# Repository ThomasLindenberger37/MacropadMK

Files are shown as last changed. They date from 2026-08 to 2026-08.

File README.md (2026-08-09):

# MacropadMK

MacropadMK is a 12-key macropad built around the Waveshare ESP32-S3-Zero. The
board combines a diode-isolated 4 × 3 keyboard matrix, three USB-C power-entry
options, and two general-purpose JST-SH connections in a compact design.

The PCB is intended for an accessible prototyping workflow: order bare boards,
assemble and validate the first units by hand, then reuse the same LCSC-aware
bill of materials for a later JLCPCB assembly run.

## Design overview

- Controller: ESP32-S3-Zero
- Keyboard: 12 switches arranged as 4 rows × 3 columns
- Isolation: one diode per switch
- Matrix direction: `COL2ROW`
- Supply rails: `BOARD_5V`, `3V3`, and `GND`
- USB-C inputs: the controller connector plus two alternative PCB connectors
- Expansion: two identically pinned 3-position JST-SH connectors

## Keyboard matrix

The switches form a 4-row by 3-column matrix. `ROW1` through `ROW4` are scanned
one at a time by driving the selected row low. `COL1` through `COL3` are inputs,
each held high by an external 10 kΩ pull-up resistor to `3V3`.

Each key is an independent branch:

```text
COLx -> switch -> diode anode -> diode cathode -> ROWx
```

The diode orientation is `COL2ROW`: the cathode, identified by the stripe on the
physical diode, points toward the row line. When a selected row is low and a key
on that row is pressed, its column input is pulled low through the switch and
diode.

| Signal group | Quantity | Scan role | External bias |
| --- | ---: | --- | --- |
| `ROW1`–`ROW4` | 4 | Driven low individually | None |
| `COL1`–`COL3` | 3 | Digital inputs | 10 kΩ to `3V3` per column |

## USB-C power architecture

The ESP32-S3-Zero already has its own USB-C connector. The PCB provides two
additional connector positions as alternative 5 V inputs:

- Horizontal/right-angle: HRO `TYPE-C-31-M-12`
- Vertical/axial: `MC-110LD-L124`, USB 2.0, 16 pins, with THT mounting tabs
- Vertical connector LCSC/JLCPCB part number: `C3039282`

The additional connectors are currently used only for power. They are still
full USB 2.0 connector parts so that the same components and footprints can be
reused in future designs with USB data support.

Each additional receptacle follows these connection rules:

- Tie all VBUS pins of that receptacle together.
- Connect all GND pins to board ground.
- Connect `CC1` to GND through its own 5.1 kΩ resistor.
- Connect `CC2` separately to GND through its own 5.1 kΩ resistor.
- Connect the connector shield to GND.
- Leave `D+`, `D-`, `SBU1`, and `SBU2` unconnected and mark them as no-connect.

Each alternative receptacle feeds the common `BOARD_5V` rail through a separate
solder bridge. `BOARD_5V` connects to the ESP32-S3-Zero 5 V pin. An optional
resettable fuse rated for approximately 1 A can be fitted ahead of the shared
rail.

Place 10 µF bulk capacitance and 100 nF decoupling close to the 5 V input. Route
VBUS with approximately 0.8–1.0 mm wide traces; 0.25 mm traces are not
recommended for a 1 A supply path.

> **Power-source warning:** The board does not provide input OR-ing or reverse-
> current isolation. Only one USB power source may be connected at a time unless
> suitable input decoupling and source isolation are added.

## Additional connectors

The board provides two identically pinned 3-position JST-SH connectors with a
1.0 mm pitch.

- KiCad symbol: `Connector_Generic:Conn_01x03`
- KiCad footprint:
  `Connector_JST:JST_SH_SM03B-SRSS-TB_1x03-1MP_P1.00mm_Horizontal`

| Pin | Signal |
| ---: | --- |
| 1 | `GND` |
| 2 | `3V3` |
| 3 | Signal |

## Sourcing and assembly strategy

Components should use LCSC `C` part numbers wherever practical. The same part
numbers can be used both for loose component orders from LCSC and for JLCPCB
assembly BOM matching.

The intended manufacturing sequence is:

1. Order unassembled prototype PCBs.
2. Hand-assemble and electrically validate the first boards.
3. Resolve ERC/DRC findings and confirm footprints, polarity, and connector
   mechanics.
4. Reuse the validated BOM for a later JLCPCB assembly order.

## Project assets

[Download the schematic as PDF](assets/MacropadMK-schematic.pdf).

MacropadMK schematic

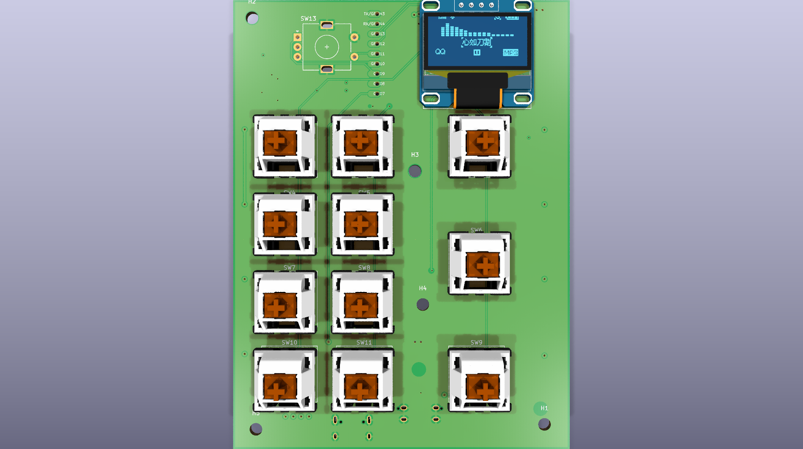
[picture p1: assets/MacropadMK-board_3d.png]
MacropadMK 3D board view


Some connector or encoder models may be absent from the rendered 3D preview if
their STEP files are not available locally. This does not affect the Gerber or
drill exports, but mechanical fit must still be checked before ordering.

## Fabrication and documentation exports

The repository contains its KiBot automation directly under `scripts/`. Docker
is required; the scripts use the KiCad 10 KiBot image configured in
`scripts/project.config.yaml`.

Generate the schematic PDF/SVG and the 3D preview:

```bash
./scripts/assets.sh
```

Generate Gerbers, drill files, BOM, placement data, the manufacturer ZIP, and
STEP models:

```bash
./scripts/fabrication.sh
```

Generated manufacturing files are written to `Fabrication/`. The validated
manufacturer archive is `Fabrication/MacropadMK-Gerber_Pack.zip`.

The relevant configuration files are:

- `scripts/project.config.yaml` — project name, KiCad image, PCB thickness, and
  mechanical-hole settings
- `scripts/kibot/config.kibot.yaml` — manufacturing outputs and production
  layers
- `scripts/kibot/kibot_assets.kibot.yaml` — documentation PDF, SVG, and 3D
  render outputs

Always run KiCad ERC and DRC and review the generated Gerbers before submitting
an order. Successful file generation does not imply that the electrical or
mechanical design is production-ready.

## Automated fabrication build

The GitHub Actions fabrication workflow generates manufacturing artifacts when
changes are pushed to the repository:



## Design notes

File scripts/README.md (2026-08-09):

# Scripts Workspace

This folder contains all automation related to:
- KiBot fabrication export
- STEP generation with mechanical holes from Gerber + Drill
- KiCad schematic field maintenance

## Structure

- `kibot/config.kibot.yaml`: Main KiBot config.
- `kibot/kibot_assets.kibot.yaml`: Assets KiBot config.
- `project.config.yaml`: Project-specific defaults (board name, output name, thickness, mechanical tools).
- `generate_step_mech.py`: Mechanical STEP generator.
- `add_lcsc_field.py`: Adds missing `LCSC` fields to placed schematic symbols.
- `fabrication.sh`: Fabrication pipeline (KiBot + mechanical STEP generator).
- `assets.sh`: Local assets pipeline (schematic + 3D render).
- `.venv/`: Local Python virtualenv used by script tooling.
- `.gitignore`: Ignore rules for script-local artifacts.

## Add missing LCSC fields

Preview the changes without modifying the schematic:

```bash
python3 scripts/add_lcsc_field.py --dry-run MacropadMK.kicad_sch
```

Apply them (close the schematic in KiCad first):

```bash
python3 scripts/add_lcsc_field.py MacropadMK.kicad_sch
```

Existing `LCSC` fields and their values remain unchanged. Power and helper symbols
such as `#PWR` and `#FLG` are skipped by default. Pass
`--include-power-symbols` if those symbols should receive the field too.

## Fabrication Script

Run:

```bash
./scripts/fabrication.sh
```

Behavior:
- Always runs inside Docker image `ghcr.io/inti-cmnb/kicad10_auto_full:latest`.

Default output name prefix comes from `output_name` in `scripts/project.config.yaml`.
If `output_name` is empty, repository folder name is used.
Override it with:

```bash
./scripts/fabrication.sh --name MyBoardName
```

Optional board base override:

```bash
./scripts/fabrication.sh --board MacropadMK
```

Optional mechanical tools override:

```bash
./scripts/fabrication.sh --mechanical-tools T5
```

## Assets Script (Local)

Run locally (uses Docker image `ghcr.io/inti-cmnb/kicad10_auto_full:latest`):

```bash
./scripts/assets.sh
```

Default asset prefix comes from `output_name` in `scripts/project.config.yaml`.
If `output_name` is empty, repository folder name is used.
Override it with:

```bash
./scripts/assets.sh --name MyBoardName
```

Optional board base override:

```bash
./scripts/assets.sh --board MacropadMK
```

## Project Config

Default config file: `scripts/project.config.yaml`

Example fields:

```yaml
board_name: MacropadMK
output_name: MacropadMK
thickness: 1.6
mechanical_tools:
docker_image: ghcr.io/inti-cmnb/kicad10_auto_full:latest
```

Both scripts read this file automatically.
CLI options always override config values.

Use a different config file:

```bash
./scripts/fabrication.sh --config scripts/project.config.yaml
./scripts/assets.sh --config scripts/project.config.yaml
```

## What `fabrication.sh` Does

1. Runs KiBot with `scripts/kibot/config.kibot.yaml`.
2. Installs `cadquery` in the Docker runtime.
3. Runs `generate_step_mech.py` to create:
   - `Fabrication/STEP/<name>-STEP_Mechanical.step`

## Manual Script Usage

```bash
scripts/.venv/bin/python scripts/generate_step_mech.py \
  --edge-gerber Fabrication/Gerber/MacropadMK-Edge_Cuts.gbr \
  --drill Fabrication/Drill/MacropadMK-drill.drl \
  --out Fabrication/STEP/MacropadMK-STEP_Mechanical.step \
  --thickness 1.6
```

To force mechanical tools explicitly:

```bash
scripts/.venv/bin/python scripts/generate_step_mech.py \
  --edge-gerber Fabrication/Gerber/MacropadMK-Edge_Cuts.gbr \
  --drill Fabrication/Drill/MacropadMK-drill.drl \
  --out Fabrication/STEP/MacropadMK-STEP_Mechanical.step \
  --thickness 1.6 \
  --mechanical-tools T3,T4
```

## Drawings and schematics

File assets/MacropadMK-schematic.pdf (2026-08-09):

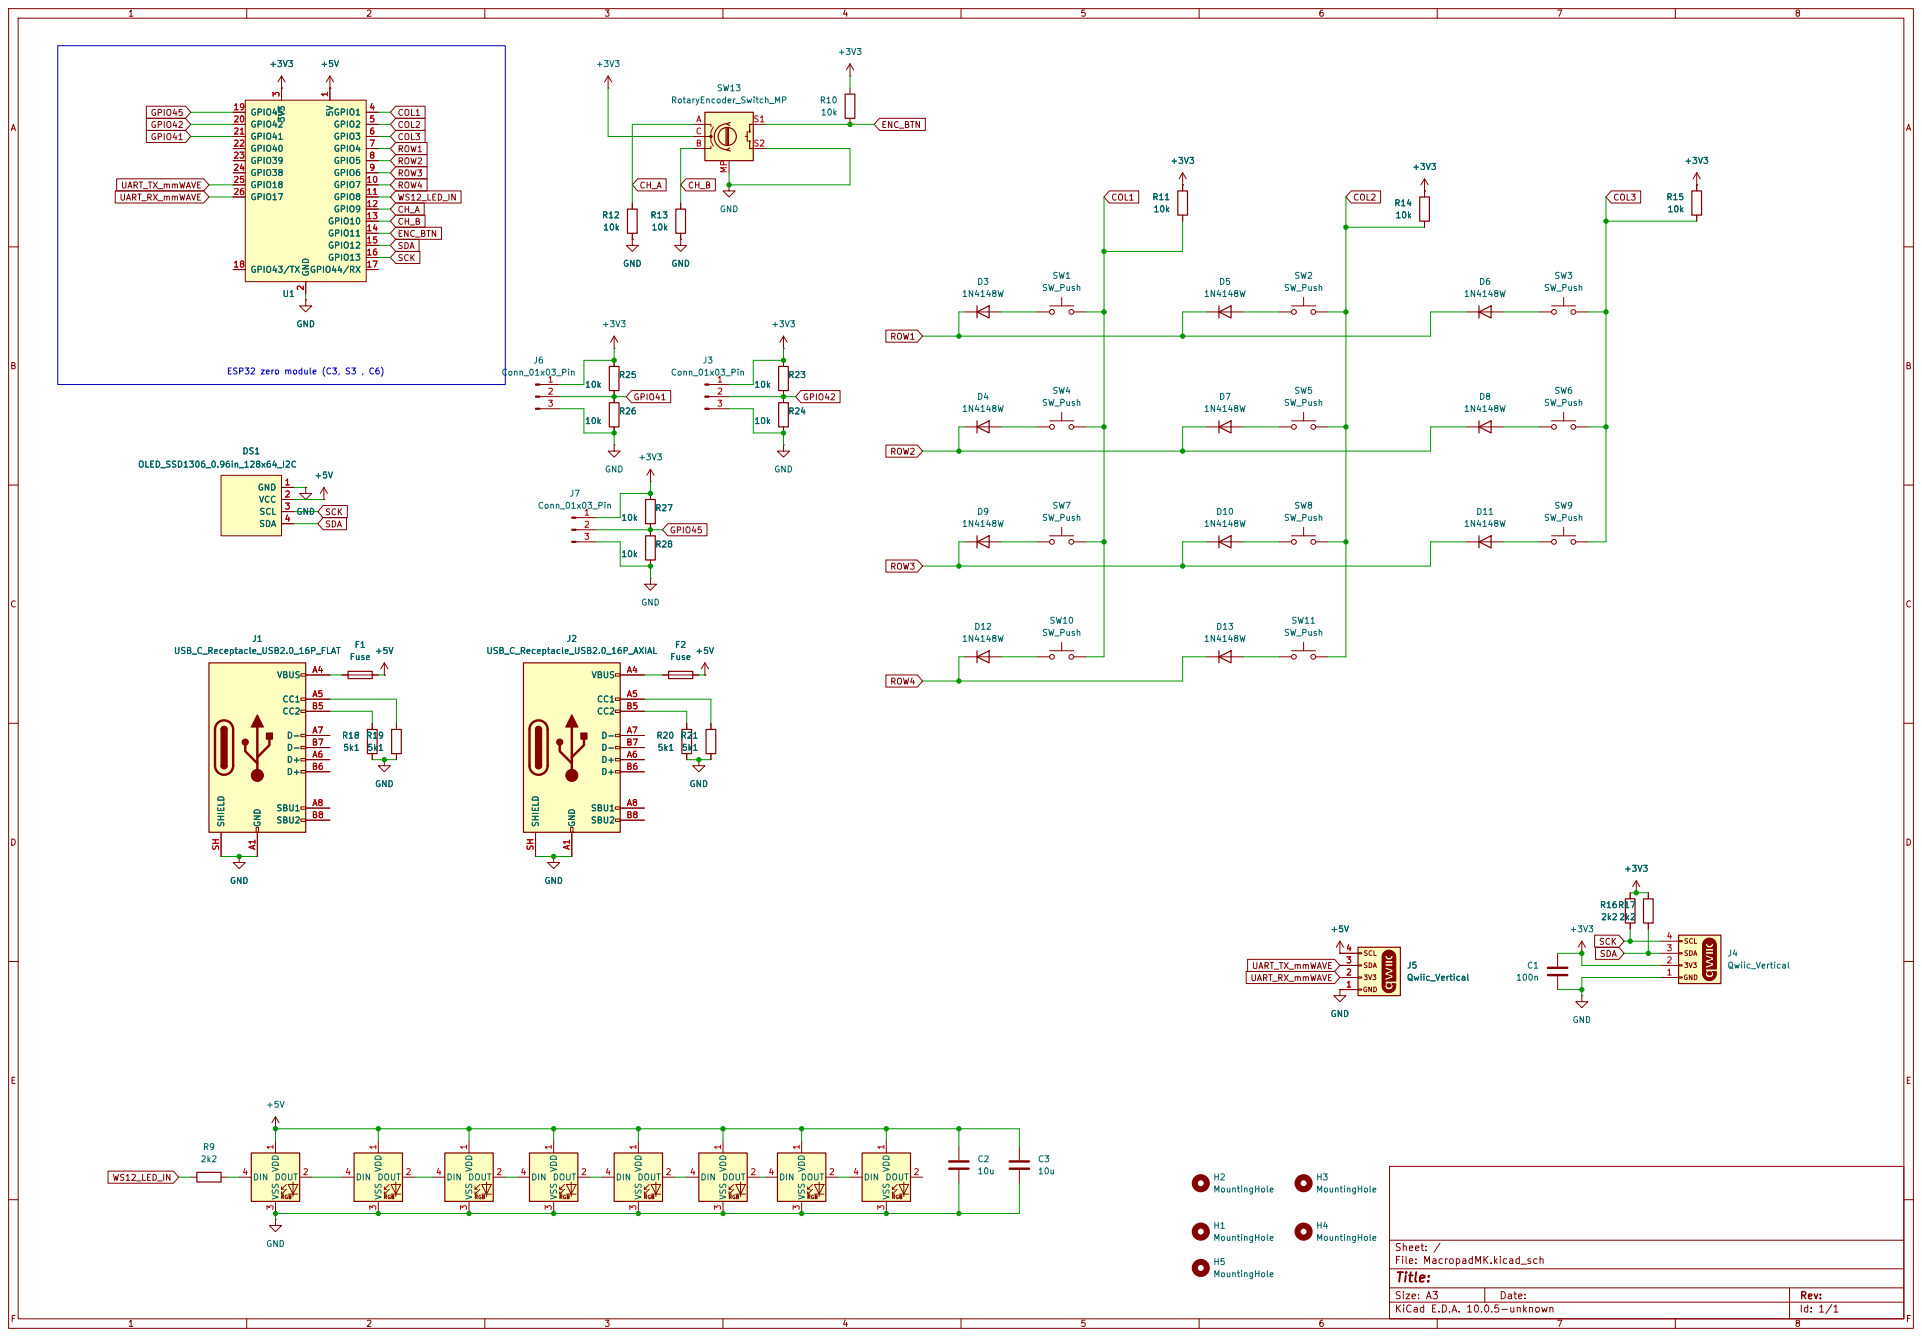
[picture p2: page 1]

3 GPIO1 4 GPIO2 5 GPIO3 6 GPIO4 7 GPIO5 8 GPIO6 9 GPIO7 10 GPIO8 11 GPIO9 12 GPIO10 13 GPIO11 14 GPIO12 15 GPIO13 16 GPIO44/RX 17 GPIO43/TX 18 GPIO45 19 GPIO42 20 GPIO41 21 GPIO40 22 GPIO39 23 GPIO38 24 GPIO18 25 GPIO17 26 +5V GND +3V3 GND GND

Size: A3 | Rev: | F Date:
KiCad E.D.A. 10.0.5-unknown | Id: 1/1

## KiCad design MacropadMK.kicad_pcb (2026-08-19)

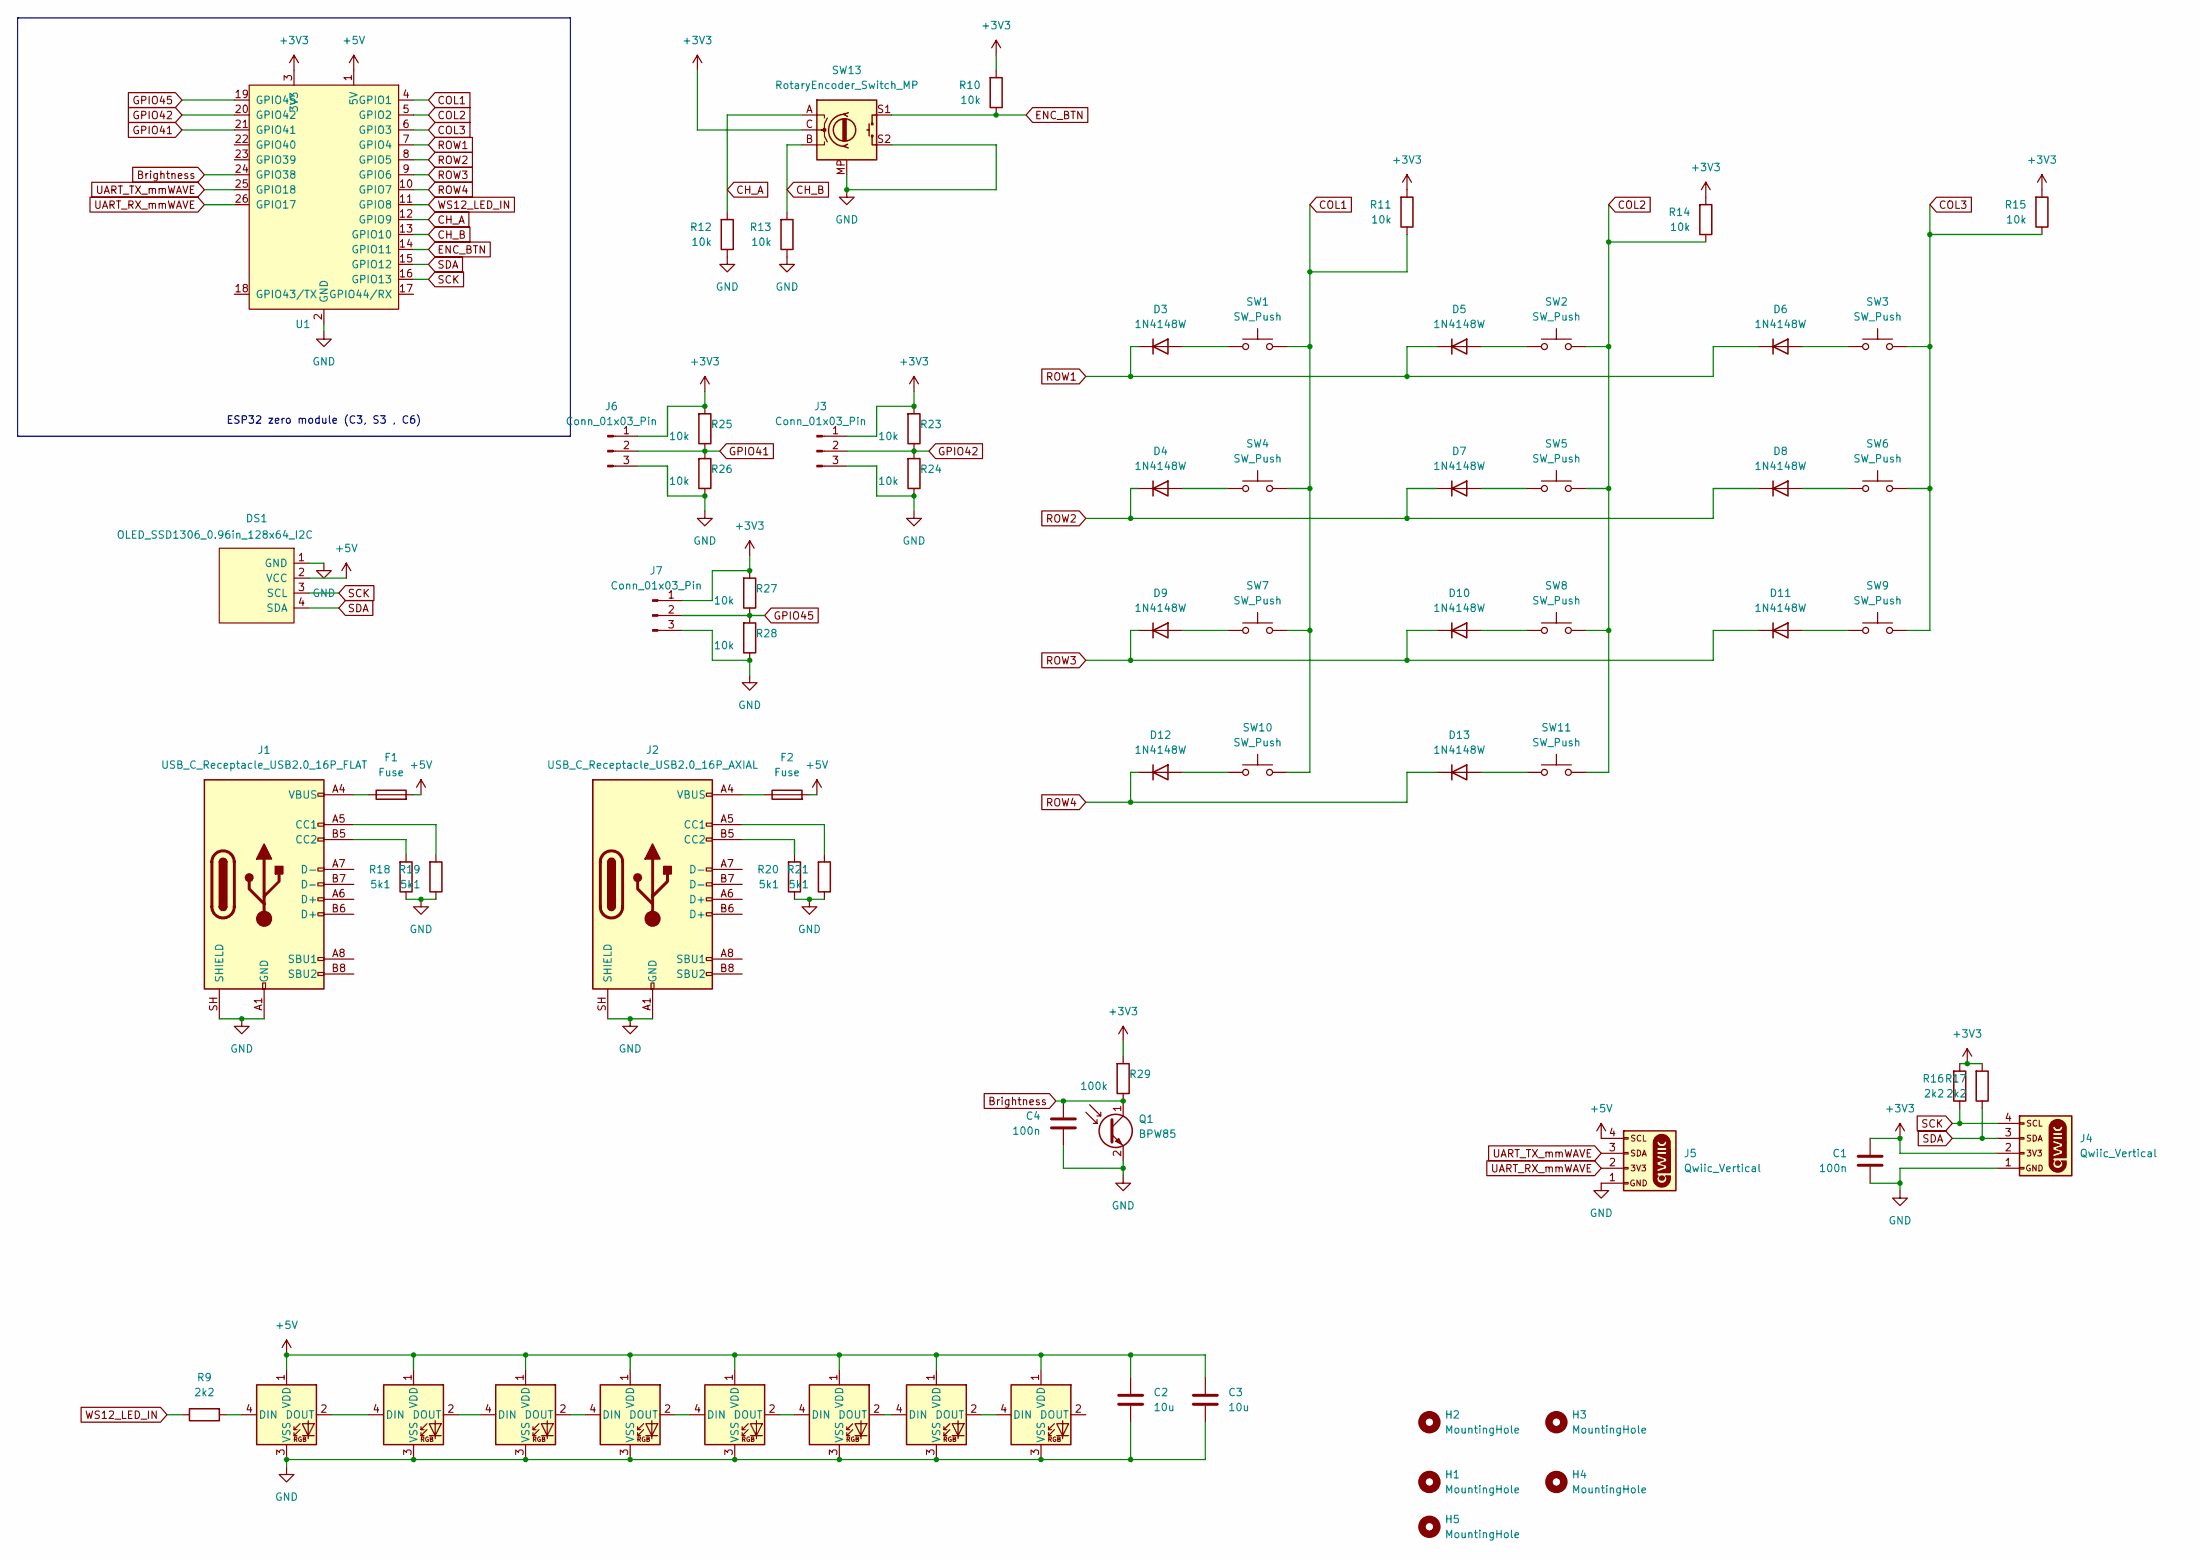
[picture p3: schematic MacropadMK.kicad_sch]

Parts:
C1, C4: 100n; C_0805_2012Metric; JLCPCB Part C6119867
C2, C3: 10u; C_0805_2012Metric
D1, D2, D14, D15, D16, D17, D18, D19: WS2812B; LED_WS2812B_PLCC4_5.0x5.0mm_P3.2mm; LCSC C22461793
D3, D4, D5, D6, D7, D8, D9, D10, D11, D12, D13: 1N4148W; D_SOD-123
DS1: OLED_SSD1306_0.96in_128x64_I2C
F1, F2: Fuse; Fuse_0805_2012Metric
H1, H2, H3, H4, H5: MountingHole; MountingHole_3.2mm_M3
J1: USB_C_Receptacle_USB2.0_16P_FLAT; USB_C_Receptacle_HRO_TYPE-C-31-M-12; LCSC C165948
J2: USB_C_Receptacle_USB2.0_16P_AXIAL; USB_C_Receptacle_JAE_DX07S024WJ3R400; LCSC MC-110LD-L124
J3, J6, J7: Conn_01x03_Pin; JST_SH_BM03B-SRSS-TB_1x03-1MP_P1.00mm_Vertical
J4, J5: Qwiic_Vertical; JST_SH_BM04B-SRSS-TB_1x04-1MP_P1.00mm_Vertical
Q1: BPW85; LED_0603_1608Metric
R9, R16, R17: 2k2; R_0603_1608Metric
R10, R11, R12, R13, R14, R15, R23, R24, R25, R26, R27, R28: 10k; R_0603_1608Metric
R18, R19, R20, R21: 5k1; R_0603_1608Metric
R29: 100k; R_0603_1608Metric
SW1, SW2, SW3, SW4, SW5, SW6, SW7, SW8, SW9, SW10, SW11: SW_Push; SW_Cherry_MX_PCB_1.00u
SW13: RotaryEncoder_Switch_MP; RotaryEncoder_Alps_EC11E-Switch_Vertical_H20mm
U1: ESP32-S3-Zero

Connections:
+3V3: C1.1, J3.1, J4.2, J6.1, J7.1, R10.2, R11.2, R14.2, R15.2, R16.2, R17.2, R23.2, R25.2, R27.2, R29.2, SW13.C, U1.3 (3V3)
+5V: C2.1, C3.1, D1.1 (VDD), D2.1 (VDD), D14.1 (VDD), D15.1 (VDD), D16.1 (VDD), D17.1 (VDD), D18.1 (VDD), D19.1 (VDD), DS1.2 (VCC), F1.2, F2.2, J5.4, U1.1 (5V)
Brightness: C4.1, Q1.1 (C), R29.1, U1.24 (GPIO38)
CH_A: R12.2, SW13.A, U1.12 (GPIO9)
CH_B: R13.2, SW13.B, U1.13 (GPIO10)
COL1: R11.1, SW1.2, SW4.2, SW7.2, SW10.2, U1.4 (GPIO1)
COL2: R14.1, SW2.2, SW5.2, SW8.2, SW11.2, U1.5 (GPIO2)
COL3: R15.1, SW3.2, SW6.2, SW9.2, U1.6 (GPIO3)
ENC_BTN: R10.1, SW13.S1, U1.14 (GPIO11)
GND: C1.2, C2.2, C3.2, C4.2, D1.3 (VSS), D2.3 (VSS), D14.3 (VSS), D15.3 (VSS), D16.3 (VSS), D17.3 (VSS), D18.3 (VSS), D19.3 (VSS), DS1.1 (GND), J1.A1 (GND), J1.A12 (GND), J1.B1 (GND), J1.B12 (GND), J1.SH (SHIELD), J2.A1 (GND), J2.A12 (GND), J2.B1 (GND), J2.B12 (GND), J2.SH (SHIELD), J3.3, J4.1, J5.1, J6.3, J7.3, Q1.2 (E), R12.1, R13.1, R18.1, R19.1, R20.1, R21.1, R24.1, R26.1, R28.1, SW13.MP, SW13.S2, U1.2 (GND)
GPIO41: J6.2, R25.1, R26.2, U1.21 (GPIO41)
GPIO42: J3.2, R23.1, R24.2, U1.20 (GPIO42)
GPIO45: J7.2, R27.1, R28.2, U1.19 (GPIO45)
unnamed: D1.4 (DIN), R9.2
unnamed: D1.2 (DOUT), D2.4 (DIN)
unnamed: D3.2 (A), SW1.1
unnamed: D4.2 (A), SW4.1
unnamed: D5.2 (A), SW2.1
unnamed: D6.2 (A), SW3.1
unnamed: D7.2 (A), SW5.1
unnamed: D8.2 (A), SW6.1
unnamed: D9.2 (A), SW7.1
unnamed: D10.2 (A), SW8.1
unnamed: D11.2 (A), SW9.1
unnamed: D12.2 (A), SW10.1
unnamed: D13.2 (A), SW11.1
unnamed: D2.2 (DOUT), D14.4 (DIN)
unnamed: D14.2 (DOUT), D15.4 (DIN)
unnamed: D15.2 (DOUT), D16.4 (DIN)
unnamed: D16.2 (DOUT), D17.4 (DIN)
unnamed: D17.2 (DOUT), D18.4 (DIN)
unnamed: D18.2 (DOUT), D19.4 (DIN)
unnamed: F1.1, J1.A4 (VBUS), J1.A9 (VBUS), J1.B4 (VBUS), J1.B9 (VBUS)
unnamed: F2.1, J2.A4 (VBUS), J2.A9 (VBUS), J2.B4 (VBUS), J2.B9 (VBUS)
unnamed: J1.A5 (CC1), R19.2
unnamed: J1.B5 (CC2), R18.2
unnamed: J2.A5 (CC1), R21.2
unnamed: J2.B5 (CC2), R20.2
ROW1: D3.1 (K), D5.1 (K), D6.1 (K), U1.7 (GPIO4)
ROW2: D4.1 (K), D7.1 (K), D8.1 (K), U1.8 (GPIO5)
ROW3: D9.1 (K), D10.1 (K), D11.1 (K), U1.9 (GPIO6)
ROW4: D12.1 (K), D13.1 (K), U1.10 (GPIO7)
SCK: DS1.3 (SCL), J4.4, R16.1, U1.16 (GPIO13)
SDA: DS1.4 (SDA), J4.3, R17.1, U1.15 (GPIO12)
UART_RX_mmWAVE: J5.2, U1.26 (GPIO17)
UART_TX_mmWAVE: J5.3, U1.25 (GPIO18)
WS12_LED_IN: R9.1, U1.11 (GPIO8)

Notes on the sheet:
ESP32 zero module (C3, S3 , C6)

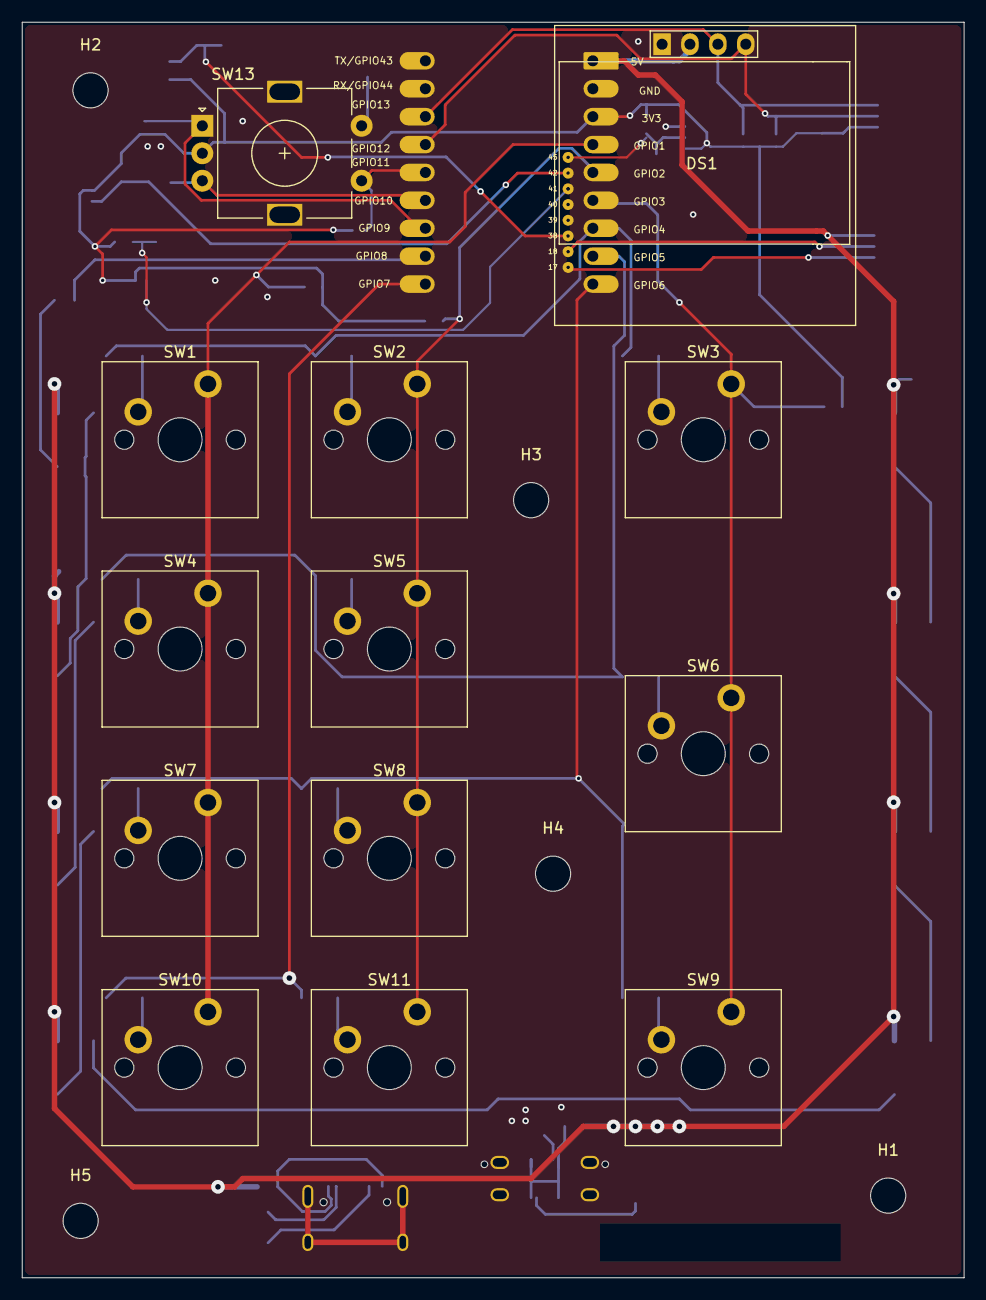
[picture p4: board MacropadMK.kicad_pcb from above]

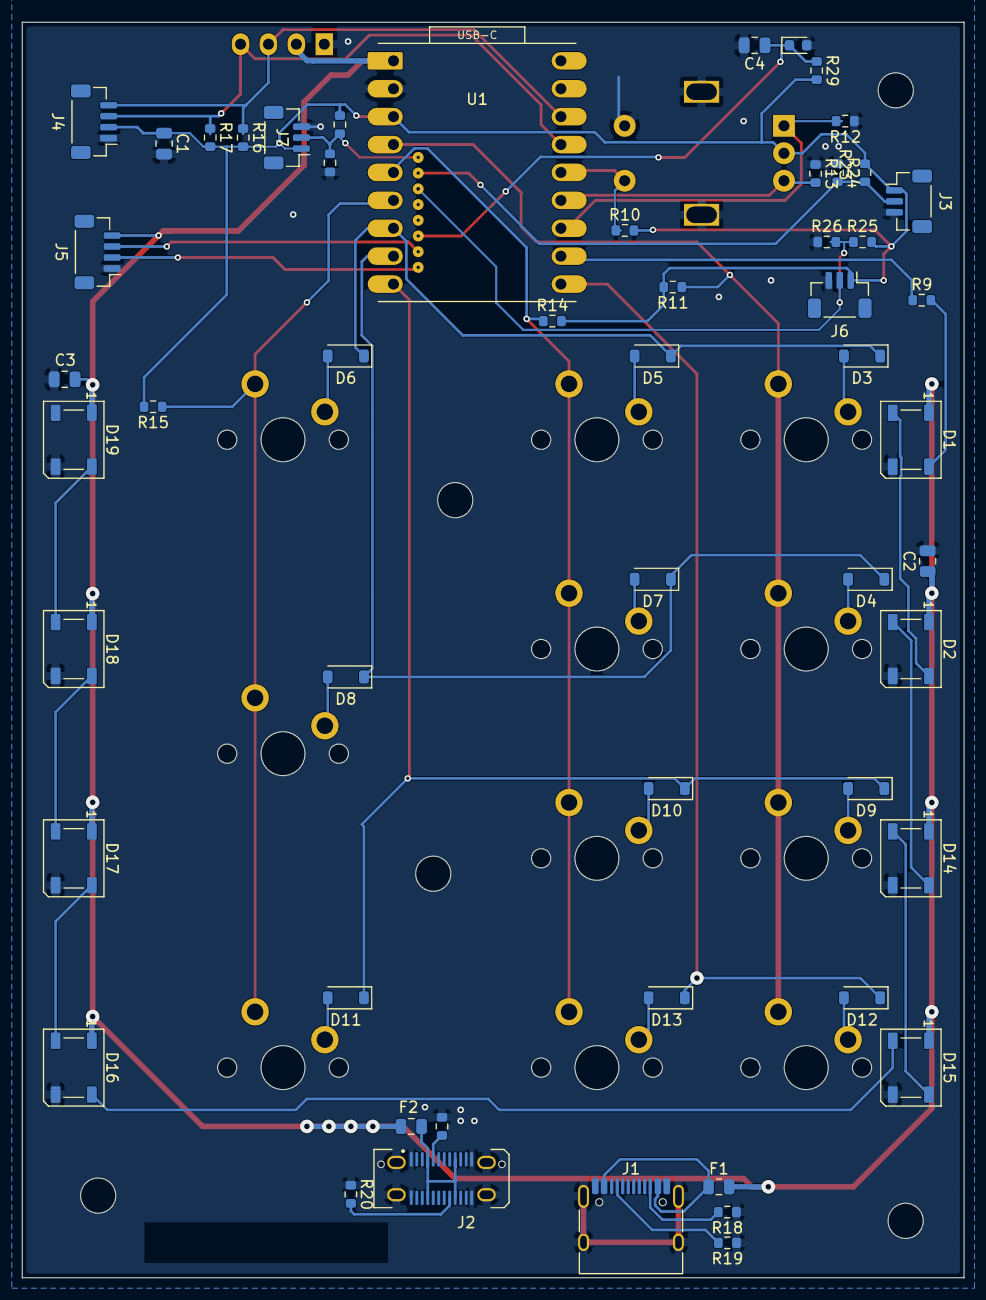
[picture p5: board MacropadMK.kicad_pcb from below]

Board: 2 copper layers, 85.7 x 114.3 mm, 72 parts (54 on the bottom side), 47 nets.

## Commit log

2026-08-01 Add updated ESP32-S3-Zero footprint
    [MacropadMK.kicad_pcb, MacropadMK.kicad_sch]
2026-08-04 added librarys
    [MacropadMK.kicad_pcb, MacropadMK.kicad_sch]
2026-08-05 add librarys
    [MacropadMK.kicad_sch]
2026-08-05 Add project-local KiCad libraries and update schematic
    [MacropadMK.kicad_sch]
2026-08-05 Save complete KiCad project state
    [MacropadMK.kicad_pcb, MacropadMK.kicad_sch]
2026-08-05 first try of layout
    [MacropadMK.kicad_pcb, MacropadMK.kicad_sch]
2026-08-09 first version with all features
    [MacropadMK.kicad_pcb, MacropadMK.kicad_sch]
2026-08-09 ready to order, all features prepared
    [MacropadMK.kicad_pcb, MacropadMK.kicad_sch]
2026-08-19 add light sensor
    [MacropadMK.kicad_pcb, MacropadMK.kicad_sch]
